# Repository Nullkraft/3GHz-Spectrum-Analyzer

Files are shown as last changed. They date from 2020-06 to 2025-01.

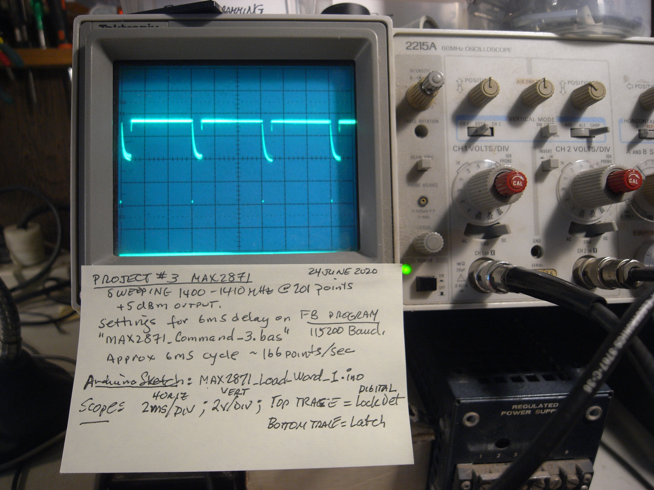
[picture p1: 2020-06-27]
Spectrum_Analyzer/Test_Data_24June2020/MAX2871_Sweep_1400-1410_201PTS.jpg

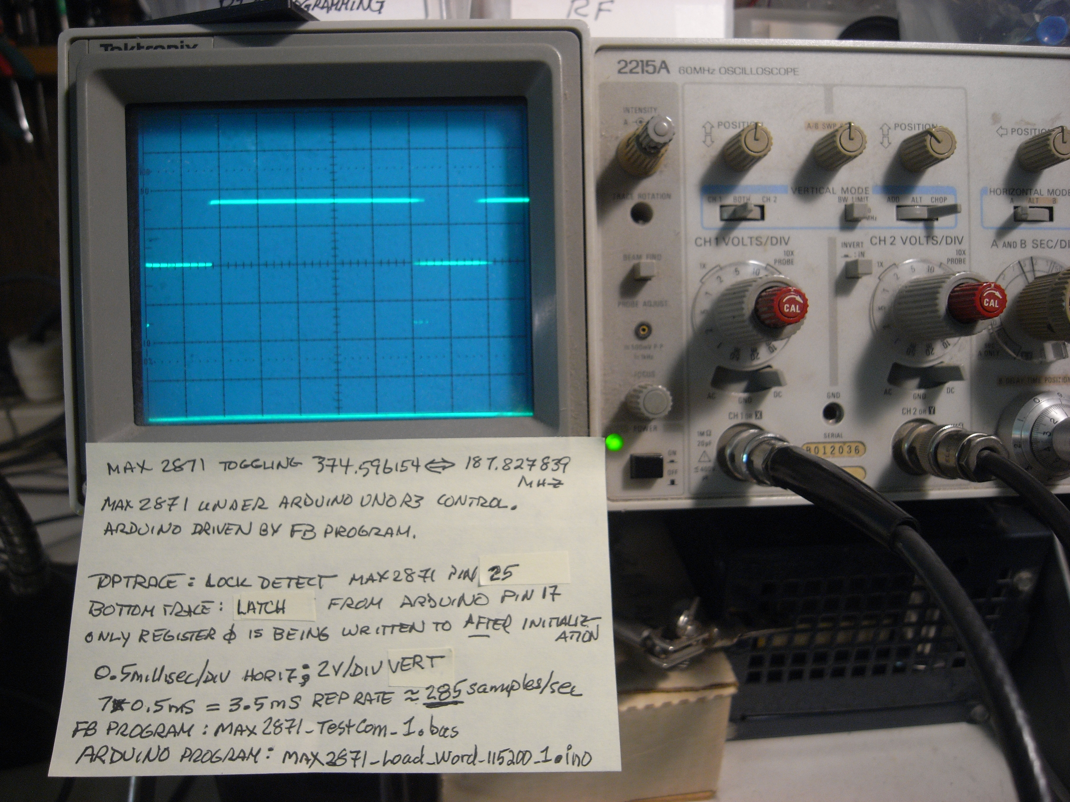
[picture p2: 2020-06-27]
Spectrum_Analyzer/Test_Data_24June2020/MAX2871_LockDet_AlternatingCode.jpg

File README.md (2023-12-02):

README for PROJECT#1 Spectrum Analyzer 22 June 2020- WN2A

A spectrum analyzer compatible with Arduino UNO R3 Microcontroller and others.

1) Schematics: are	spectrumwvi-page1.sch
					specrtumwvi-page2.sch
					specrtumwvi-page3.sch
					specrtumwvi-page4.sch
					specrtumwvi-page5.sch
    
   A small team with Mark Stanley and Mike Masterson using gEDA gschem schematics
    
2) This design is intended to meet the following preliminary specifications:
  * Frequency Range: 23.5 to 3000 MHz.
  * Spurious Free Dynamic Range: 72 dBC
  * Powered either by External +7 ~ +13V
  * Arduino driver provided allowing for serial command & control
  * Dual XTAL Reference allows minimizing Frac-N spurs.
  * Individual AZ1117 low-noise regulators for Digital, RF and VCO
  * Compatible with various Arduinos using the UNO pin arrangement

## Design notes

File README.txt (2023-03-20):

This is the First set of Documents for the Spectrum Analyser project 19Feb 2018

Goals:
1) Frequency Range: DC-3000 MHz
2) Dynamic Range: 72 dB min; 90 dB typ
3) Operating signal level <0dBm;
   Max RF Input +10dBm DC-48MHz ; +15 dBm 48-3000MHz
4) IF Bandwidths : A:~ 300KHz B:~ 7.5 KHz (Dual simultaneous IF's)
5) Power Supply requirement: +12 VDC at 1 A typ
6) Interface: Serial SPI Bus 3-wire . Clock and Data Common,
   LE signal is specific to the device being programmed.
7) Controllable from any Arduino UNO R3 or better microcontroller/ FPGA.

TODO's
1) Proof-Read this package
2) **DONE** - Determine Reference source,(i.e. Crystal Oscillator module at Frequency X)
3) Determine Shielding/Grounding requirements for PCB layout
4) Add information to the spread-sheet cost estimate (columns G and H).

In this package:
1) This README.pdf
2) SA_BlockDiagram.pdf
3) SA_Schematic_1.pdf
4) SA_Schematic_2.pdf
5) SA_Schematic_3.pdf
6) SA_Schematic_4.pdf
7) SA_Schematic_5.pdf
8) SA_Schematic_6.pdf
9) SA_Schematic_7.pdf
10) SA_Schematic_8.pdf

Most of the components used on this project are available, but the folder
for these is >27 Meg in size.

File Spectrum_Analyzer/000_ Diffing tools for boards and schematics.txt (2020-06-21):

From the Article: Visual diffs with gEDA, git, and GitHub
http://blog.benbergman.ca/2012/05/17/visual-diffs-with-geda-git-and-github/

Edit: Of course not 20 minutes after I publish this post I discover schdiff, a tool bundled with gEDA since the start of 2012 that is designed to hook into git-difftool to provide a visual diff of gschem .sch files. One format down, some more to go.

Edit 2: Less than a day later and I discover there is also a pcbdiff tool on my computer that came with gEDA pcb. In Arch Linux, it installs to /usr/share/pcb/tools/pcbdiff, but it is not in the path, so in my .bashrc I just added 'export PATH="$PATH:/usr/share/pcb/tools"' at the end.  I feel pcbdiff outputs images that are too low a resolution, plus it can't handle when the .pcb files change in physical size, so I might submit a patch or two. Long story short, now I just need to make a script that auto-calls these diff tools based on the file type.

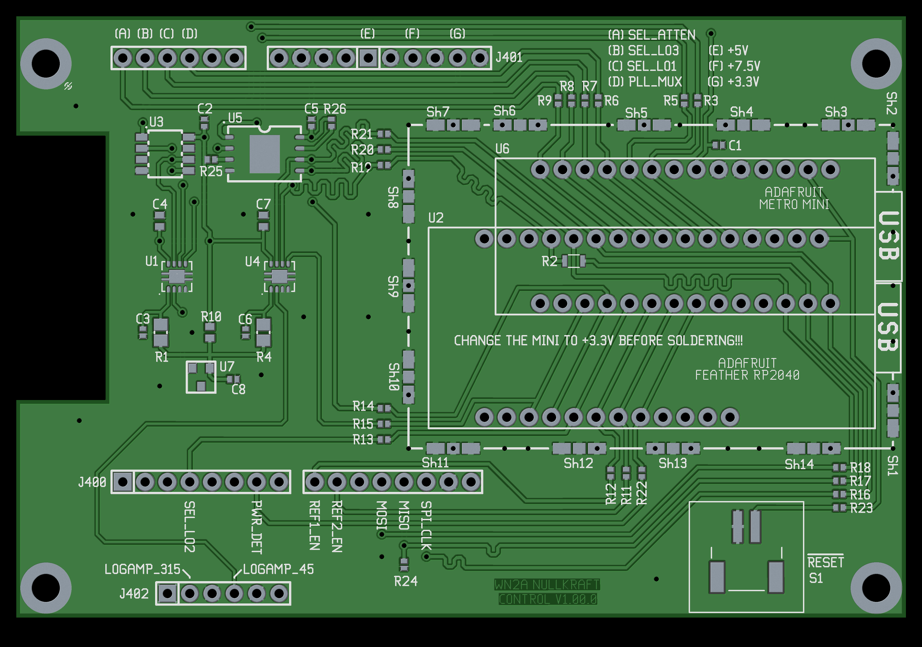
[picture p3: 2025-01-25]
Spectrum_Analyzer/Schematics/board_images/controlvwi_TOP.png

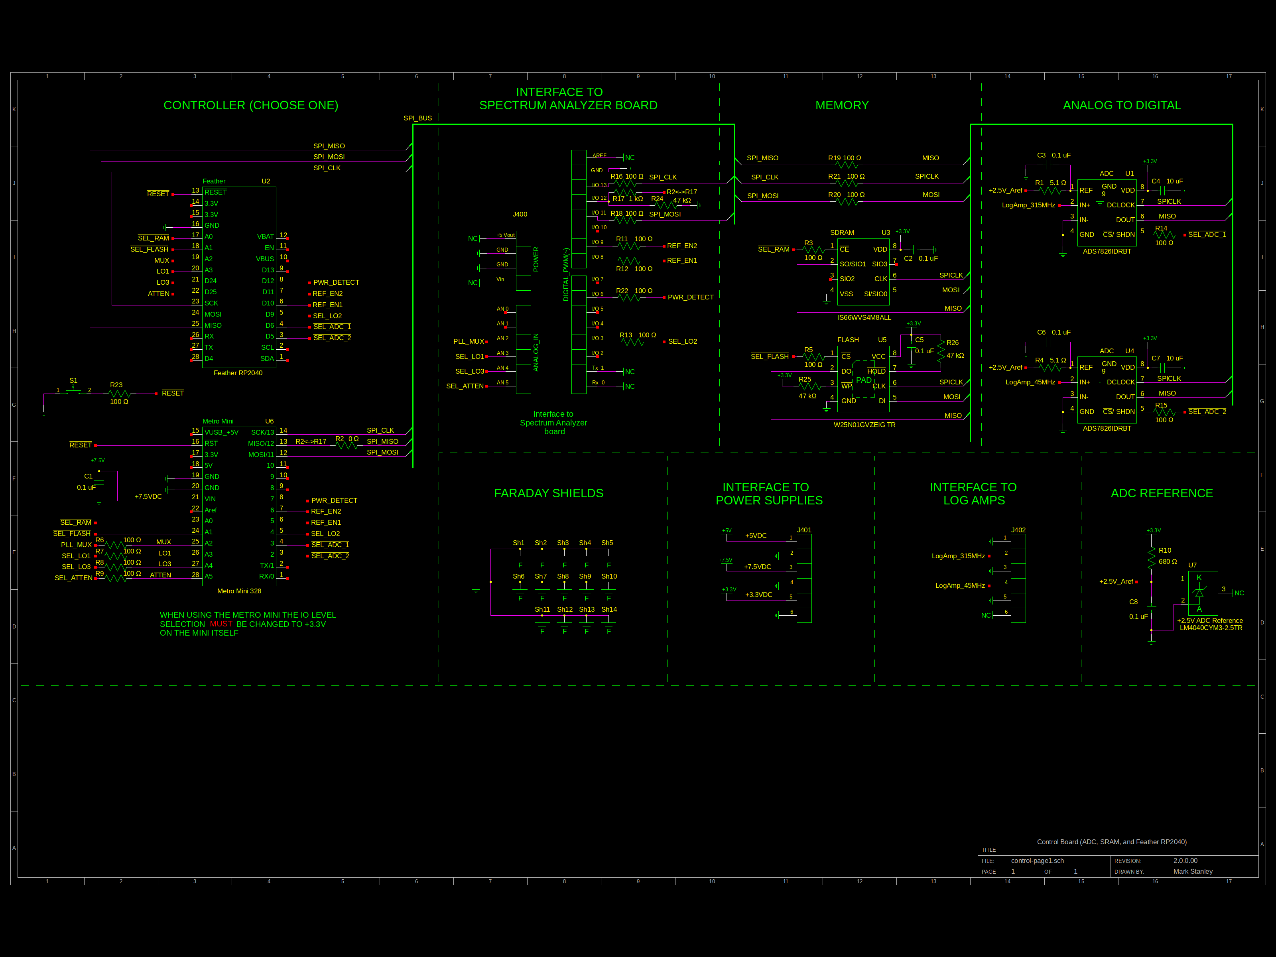
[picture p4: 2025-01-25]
Spectrum_Analyzer/Schematics/board_images/control-schem.png

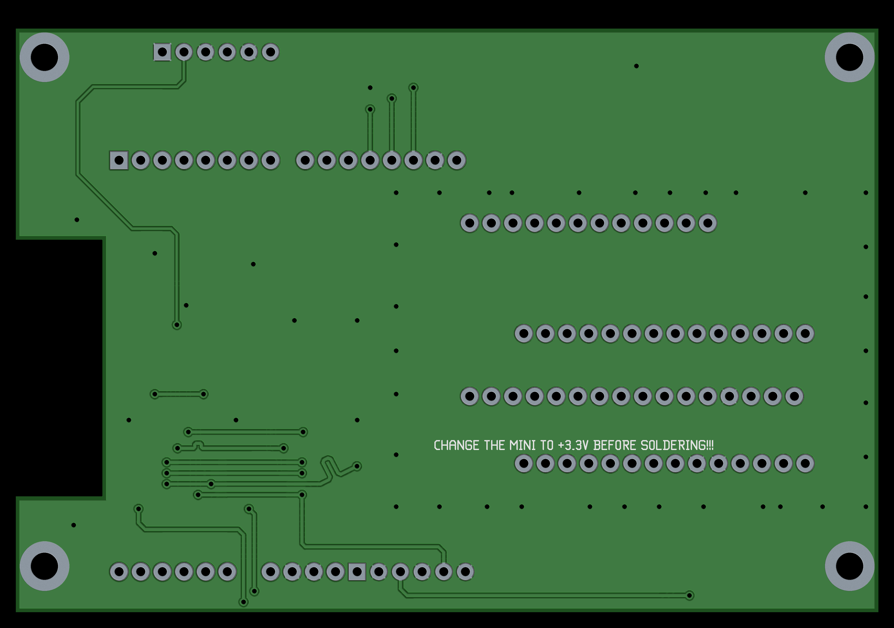
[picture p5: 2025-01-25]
Spectrum_Analyzer/Schematics/board_images/controlvwi_BOT.png

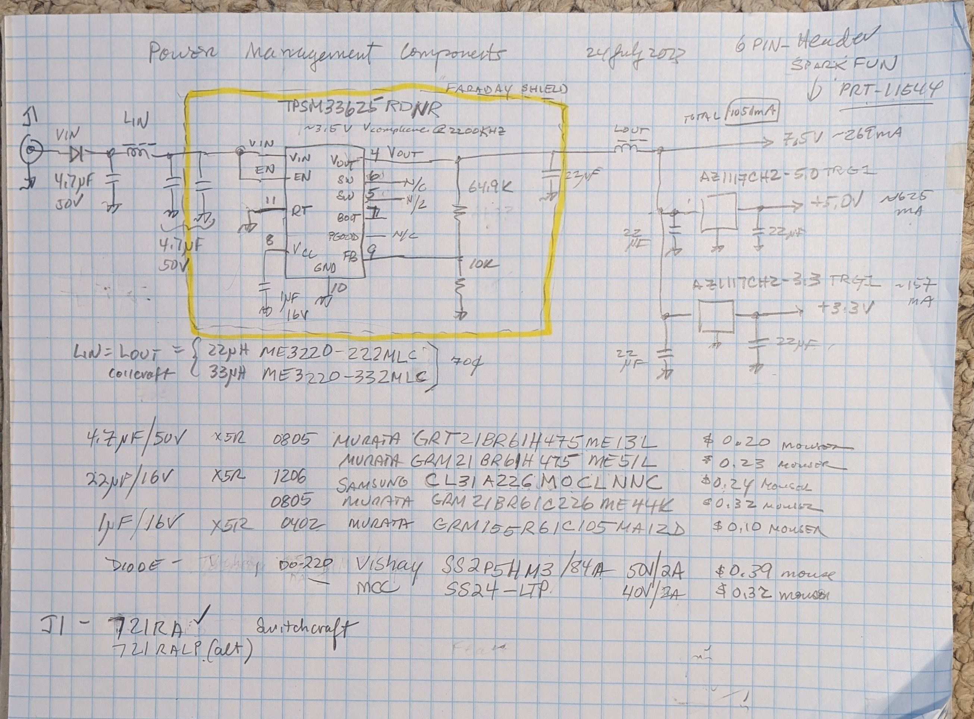
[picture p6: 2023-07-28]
Spectrum_Analyzer/Schematics/Schematics - Original Hand Drawn/Power Supply board.jpg

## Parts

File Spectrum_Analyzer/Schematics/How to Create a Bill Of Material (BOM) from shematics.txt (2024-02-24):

Create a Bill Of Material (BOM) from shematics

Open the terminal and enter the following commands :

   - cd /your_project

   - touch attribs : create a file that will contain the attributes you want to include in the BOM

   - touch bom.txt : Create the txt file

   - edit attribs to see what you want to add at your build. (value, footprint) Refdes is automatically added.

   - gnetlist -g bom2 -o bom.txt NiX1-V1-MB.sch (or the name of the actual file)

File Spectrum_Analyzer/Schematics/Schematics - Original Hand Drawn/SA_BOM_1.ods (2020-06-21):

SPECTRUM ANALYZER BOM : COMPONENTS
ITEM | DESCRIPTION | PART NO | MANF | REF DES | QTY | COST EA | COST EXT | SCH#
101 | Digital Step Atten | PE43711 | PSEMI | U101 | 1 |  |  | 1
102 | LOW PASS FILTERS | LFCN3000D+ | MCL | FL101,FL102 | 2 |  |  | 1
103 | GAIN BLOCKS | ERA-2SM+ | MCL | U102 | 1 |  |  | 1
104 | MIXER,DBM | SIM-83+ | MCL | U103 | 1 |  |  | 1
105 | CAPS,SMT BB | 530L104KT16T | ATC | C101,C102,C103,C107,C108 | 5 |  |  | 1
106 | CAPS, SMD 0.1uF,16V,X7R | 885012205037 | WURTH | C104,C106,C110 | 3 |  |  | 1
107 | CAPS,SMD,22pF,0402 | 885012005057 | WURTH | C105,C109 | 2 |  |  | 1
108 | RES, SMD, 1K | CRCW04021K00FKEDC | VISHAY | R101,R102,R103 | 3 |  |  | 1
109 | RES,SMD,51,1/8W | CRCW080551R0FKEA | VISHAY | R104,R105,R106,R107 | 4 |  |  | 1
110 | IND, SMD,22nH,0603 | 0603CS-R22XJEU | COILCRAFT | L101 | 1 |  |  | 1
111 | GAIN BLOCKS | ERA-1SM+ | MCL | U104 | 1 |  |  | 1
112 | IND, SMD,3.3nH,0402 | 0402CS-3N3XJEU | COILCRAFT | L102 | 1
 |  |  |  |  |  |  |  | 1
201 | GAIN BLOCKS | ERA-2SM+ | MCL | U201 | 1 |  |  | 2
202 | MIXER,ACTIVE | LTC5562IUC#TRPBF | ANALOG | U202 | 1 |  |  | 2
203 | BANDPASS FILTERS | 3600BP15M600 | JTI | FL201,FL202 | 2 |  |  | 2
204 | TRANSFORMER | TC1-1-43+ | MCL | T201 | 1 |  |  | 2
205 | TRANSFORMER | TC8-1-10LN+ | MCL | T202 | 1 |  |  | 2
206 | IND,SMD,10nH,0402 | 0402CS-10NXJEU | COILCRAFT | L201 | 1 |  |  | 2
207 | IND,SMD, 100nH,0603 | 0603CS-R10XJEU | COILCRAFT | L202,L203 | 2 |  |  | 2
208 | CAP,SMD,22pF,NP0,0402 | 885012005057 | WURTH | C201-C204;C211 | 5 |  |  | 2
209 | RES,SMD,51,1/8W | CRCW080551R0FKEA | VISHAY | R201,R207 | 2 |  |  | 2
210 | CAP, SMD 0.1uF,16V,X7R,0402 | 885012205037 | WURTH | C214,C216,C213,C206 | 4 |  |  | 2
211 | CAP,SMD,0.01uF,16V,X7R,0402 | 885012205031 | WURTH | C205,C210 | 2 |  |  | 2
212 | RES,SMD,300,0402 | CRCW0402300RFKED | VENKEL | R202-R205 | 4 |  |  | 2
213 | RES,SMD,36,0402 | CRCW040236R0JNED | VENKEL | R206 | 1 |  |  | 2
301 | FILTERS,SAW,315MHz | B39321B3741H110 | RF360 | FL301,FL302 | 2 |  |  | 3
302 | GAIN BLOCKS | ERA-2SM+ | MCL | U301,U302,U304 | 3 |  |  | 3
303 | MIXER,ACTIVE | LTC5562IUC#TRPBF | ANALOG | U303 | 1 |  |  | 3
304 | TRANSFORMER | TC8-1-10LN+ | MCL | T301 | 1 |  |  | 3
305 | FILTER,XTAL 45 MHz | ECS-75SMF45A7.5B | ECS | FL303,FL304 | 2 |  |  | 3
306 | RES,SMD 100, 0402 | CRCW0402100RJNED | VISHAY | R303 | 1 |  |  | 3
307 | RES,SMD 110,1/4w | CRCW1206110RFKEA | VISHAY | R301,R302,R309,R310,R311,R312 | 6 |  |  | 3
308 | IND,SMD,68nH,0603 | 0603CS-68NXJEU | COILCRAFT | L301-L304 | 4 |  |  | 3
309 | CAP,SMD,1.8pF,NP0, 0402 | GCM1555C1H1R82A16D | MURATA | C301,C302,C303,C304 | 4 |  |  | 3
310 | CAP,SMD,20pF,NP0,0402 | GCM1555C1H200JA01D | MURATA | C331,C332 | 2 |  |  | 3
311 | CAP,SMD,30pF,NP0,0402 | GCM1555C1H300JA01J | MURATA | C323,C324,C325,C326 | 4 |  |  | 3
312 | CAP,SMD,TBD pF | SAT |  | C327-C330 | 4 |  |  | 3
313 | CAP,SMD,0.01uF,X7R,0402 | 885012205031 | WURTH | C308-C311,C316,C317,C320,C322,C335-C338 | 12 |  |  | 3
314 | CAP,SMD,0.1uF,X7R,0402 | 885012205037 | WURTH | C321,C333,C334 | 3 |  |  | 3
315 | IND,SMD,36nH,0402 | 0402CS-36NXJEU | COILCRAFT | L305,L306 | 2 |  |  | 3
316 | IND,SMD,100nH,0603 | 0603CS-R10XJEU | COILCRAFT | L307,L308 | 2 |  |  | 3
317 | IND,SMD,390nH,0805 | 0805CS-391XjEU | COILCRAFT | L309,L311-L314 | 5 |  |  | 3
401 | Logarithmic Amplifiers | AD8307ARZ | ANALOG | U401,U402 | 2 |  |  | 4
402 | A/D CONV 2-CH | AD7887ARMZ | ANALOG | U403 | 1 |  |  | 4
404 | CAP,SMD,4.7pF,0402,25V,NP0 | 885012005038 | WURTH | C401 | 1 |  |  | 4
405 | CAP,SMD,47pF,0402,25V,NP0 | 885012005044 | WURTH | C402 | 1 |  |  | 4
406 | CAP,SMD,5pF,0402,50V,NP0 | GCM1555C1H5R0CA16D | MURATA | C403 | 1 |  |  | 4
407 | CAP,SMD,39pF,0402,50V,NP0 | GCM1555C1H390JA6D | MURATA | C404 | 1 |  |  | 4
408 | IND,SMD,82nH,0805 | 0805CS-820XJEU | COILCRAFT | L401 | 1 |  |  | 4
409 | IND,SMD,680nH,0805 | 0805CS-681XJEU | COILCRAFT | L402 | 1 |  |  | 4
410 | CAPS, SMD 0.1uF,16V,X7R | 885012205037 | WURTH | C405-C408;C411,C412 | 6 |  |  | 4
411 | RES, SMD, 1K | CRCW04021K00FKEDC | VISHAY | R403,R404 | 2 |  |  | 4
412 | RES, SMD,4.7 ohm | CRCW04024R70JNED | VISHAY | R401,R402,R405 | 3 |  |  | 4
413 | RES, SMD, 1K | CRCW04021K00FKEDC | VISHAY | R406-R409 | 4 |  |  | 4
501 | IC,PLL WITH VCO SYNTH 6800MHz | ADF4356BCPZ | ANALOG | U501 | 1 |  |  | 5
502 | OP AMP,RAIL TO RAIL | AD8605ARTZ | ANALOG | U502 | 1 |  |  | 5
503 | CAP,SMD,10pF,NP0,0402 | 885012005055 | WURTH | C501,C502,C503 | 3 |  |  | 5
504 | CAPS, SMD 0.1uF,16V,X7R | 885012205037 | WURTH | C504-C512 | 9 |  |  | 5
505 | CAP,SMD,10pF,NP0,0402 | 885012005055 | WURTH | C513 | 1 |  |  | 5
506 | CAP,SMD,1pF,NP0,0402 | CU10Y11R0BATUA | AVX | C514 | 1 |  |  | 5
507 | RES, SMD, 1K,0402 | CRCW04021K00FKEDC | VISHAY | R501-R503 | 3 |  |  | 5
508 | RES,SMD,560,0402 | CRCW0402560RFKED | VISHAY | R504 | 1 |  |  | 5
509 | RES,SMD,150k,0402 | CRCW0402150KJNED | VISHAY | R505 | 1 |  |  | 5
510 | CAP,SMD,10pF,NP0,0402 | 885012005055 | WURTH | C515-C516 | 2 |  |  | 5
511 | IND, SMD,3.3nH,0402 | 0402CS-3N3XJEU | COILCRAFT | L501 | 1 |  |  | 5
512 | CAP,SMD,1nF,0603,16V,NP0 | 885012006029 | WURTH | C517 | 1 |  |  | 5
601 | IC,PLL WITH VCO SYNTH 4400MHz | ADF4355-2BCPZ | ANALOG | U601 | 1 |  |  | 6
602 | OP AMP,RAIL TO RAIL | AD8605ARTZ | ANALOG | U602 | 1 |  |  | 6
603 | CAP,SMD,10pF,NP0,0402 | 885012005055 | WURTH | C601,C602,C603 | 3 |  |  | 6
604 | CAPS, SMD 0.1uF,16V,X7R | 885012205037 | WURTH | C604-C612 | 9 |  |  | 6
605 | CAP,SMD,10pF,NP0,0402 | 885012005055 | WURTH | C613 | 1 |  |  | 6
606 | CAP,SMD,1pF,NP0,0402 | CU10Y11R0BATUA | AVX | C614 | 1 |  |  | 6
607 | RES, SMD, 1K,0402 | CRCW04021K00FKEDC | VISHAY | R601-R603 | 3 |  |  | 6
608 | RES,SMD,560,0402 | CRCW0402560RFKED | VISHAY | R604 | 1 |  |  | 6
609 | RES,SMD,150k,0402 | CRCW0402150KJNED | VISHAY | R605 | 1 |  |  | 6
610 | CAPS,SMD,22pF,0402,NP0 | 885012005057 | WURTH | C615,C616 | 2 |  |  | 6
611 | CAP,SMD,1nF,0603,16V,NP0 | 885012006029 | WURTH | C617 | 1 |  |  | 6
701 | IC,PLL WITH VCO SYNTH 4400MHz | ADF4355-2BCPZ | ANALOG | U701 | 1 |  |  | 7
702 | OP AMP,RAIL TO RAIL | AD8605ARTZ | ANALOG | U702 | 1 |  |  | 7
703 | CAP,SMD,10pF,NP0,0402 | 885012005055 | WURTH | C701,C702,C703 | 3 |  |  | 7
704 | CAPS, SMD 0.1uF,16V,X7R | 885012205037 | WURTH | C704-C712 | 9 |  |  | 7
705 | CAP,SMD,10pF,NP0,0402 | 885012005055 | WURTH | C713 | 1 |  |  | 7
706 | CAP,SMD,1pF,NP0,0402 | CU10Y11R0BATUA | AVX | C714 | 1 |  |  | 7
707 | RES, SMD, 1K,0402 | CRCW04021K00FKEDC | VISHAY | R701-R703 | 3 |  |  | 7
708 | RES,SMD,560,0402 | CRCW0402560RFKED | VISHAY | R704 | 1 |  |  | 7
709 | RES,SMD,150k,0402 | CRCW0402150KJNED | VISHAY | R705 | 1 |  |  | 7
710 | CAPS,SMD,22pF,0402,NP0 | 885012005057 | WURTH | C715,C716 | 2 |  |  | 7
711 | CAP,SMD,1nF,0603,16V,NP0 | 885012006029 | WURTH | C717 | 1 |  |  | 7
801 | IC,REGULATOR,ADJ,1.5AMP,TO-220 | LM317T/NOPB | TI | U801-U803 | 3 |  |  | 8
802 | CAP,SMD,0.1uf, 25V,0603,X7R | 885012206071 | WURTH | C801-C803 | 3 |  |  | 8
803 | CAP,SMD,1.0uF,16V,0603,X7R | 885012206052 | WURTH | C804-C806 | 3 |  |  | 8
804 | RES,SMD,240,0603 | CRCW0603240RFKEB | VISHAY | R801-R803 | 3 |  |  | 8
805 | RES,SMD,1.2K,0603 | CRCW06031K21FKEB | VISHAY | R804 | 1 |  |  | 8
806 | RES,SMD,715,0603 | CRCW0603715RFKEA | VISHAY | R805 | 1 |  |  | 8
807 | RES,SMD,390,0603 | CRCW0603390RJNEB | VISHAY | R806 | 1 |  |  | 8
808 | DIODE,SMD,50V,2AMP | MURA105T3G | ONSEMI | D801 | 1 |  |  | 8

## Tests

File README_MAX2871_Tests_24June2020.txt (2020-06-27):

PROJECT#3 MAX2871 Synthesizer Tests 24June2020 WN2A

1) List of files in this folder:

   A) Arduino UNO R3 Code:  MAX2871_Load_Word_115200_1.ino
                    All tests reported here done with this program.
   
   B) FB Host Code:  Used for static (Manual) and dynamic (Toggling)
                   MAX2871_Load_Word_115200_1 (Linux Executable)
                   MAX2871_Load_Word_115200_1.bas  (FB source code)
                   
   C) FB Host Code: Used to Command a single frequency manually or sweep.
                   MAX2871_Command_3 (Linux Executable)
                   MAX2871_Command_3.bas (FB source code)
                   
   D) Screenshot of MAX2871_Command_3 running: MAX2871_Command_3_Window_1.png                
                   Note that the Arduino program sends an ID messgae to the Host 
                   program, after the Arduino is running.
                   Also, the sweep rate can be seen in this report as 
                   201 Points/Sweep x 204 sweeps= 41004 total sweeps, in 254 seconds
                   or ~161.4 points/second, or ~6.2 milliseconds/point.
                   That makes sense as the FB program was set for a 6 millisecond delay
                   resulting about the same rep rate. Setting the program for 5 or less
                   millisecond delay results is lost bytes. This as found to be a problem
                   most likely with the Arduino sketch, and the way it fetches serial
                   data. This results in limiting the sweep time. See comments (2B) below.
                   
   E) Oscilloscope trace of PROJECT#3 running with  A) and B).
                  File:  MAX2871_LockDet_AlternatingCode.jpg
                  This was the best case switching I observed, toggling between two
                  frequencies, about 3.5 milliseconds. Attempting to toggle any faster
                  than this resulted in breakup (lost bytes) from the Host to Arduino. 
                  This is related to the sweep time issue in D) . See note 2B.
                  
                   Both frequencies chosen in Fractional-N mode. Observing
                  either frequency (when manually i.e. statically toggled) looked clean
                  on my spectrum analyzer.  
                  
   F) Oscilloscope trace of PROJECT#3 running with  A) and C).   This is in the Frequency
                  Sweep mode, being driven by the FB program.
                  You can see the ~6.2 millisec rep rate. Setting the Host program for
                  5 or less millisec delay results in breakup.
                  
   G) MAX2871_1400-1410_201PTS_1.mpg. Video of the sweep mode A) and C). Sweeping 1400-1410MHz
                  201 points. 
                  
2) Notes:

   A) This part does give stable output measured on my Frequency Counter (23.5 to 500MHz+) and
      also viewed on an old HP8558B Spectrum Analyser to over 1500 MHz. Power was about +3dBm average.
      Spurious could not be measured accurately, due to equipment limitations, but looks better than
      -60 dBc.
      
   B) Both Laptops (Dell Mini Netbook and MacBook Pro) ran FreeBasic Host programs on Puppy Linux Slacko
      version 6.3.2. Both Laptops could deliver 115200 Baud Commands via the USB bus, with or without any
      delay added in the Host program. The Host program/Laptops showed no sign of breakup, and the Arduino
      Rx LED stays lit, regardless of the delay setting from 0 to 10 milliseconds.
        My suspicion is with my Arduino Sketch MAX2871_Load_Word_115200_1.ino (code snippet below):
        
        void loop() {
                while (Serial.available()) {  //wait for serial
              delayMicroseconds(1000);        // give it a millisec to fill buffer
              char c = Serial.read();         //read in a byte and convert to char
              readString += c;                // concatenate 
               }
          if (readString.length() >0) {
          z=readString.toInt();
          readString=""; 
          q=z/65536;
     delayMicroseconds(10);
     digitalWrite (strobe, LOW);
     digitalWrite (strobe, HIGH);
     delayMicroseconds(10);
     digitalWrite (strobe, LOW);
 Shifty(x);                                  // calls the Shift Out Routine
 }
}

          I commented out the serial receive lines above. While this code can receive each byte, and
      preform the byte>char>Integer conversions quickly and without any issues, the problem
      may be in identifying which is the first byte in a 32-bit word. The way this seems to work is that
      for a delay of ~5-6 milliseconds between words, it has no problem. The "blank time" easily
      allows for buffer clearing. Reducing this blank time to <5 milliseconds results in overwhelming
      the serial buffer (with this sketch code).
        To be sure, I do not use the Serial.print commands in this loop structure, and I do not enable 
      the serial monitor. That would have mde matters worse. Possibly, there is better Arduino code 
      that can be used here, so sweep times can be possibly improved toward ~3 milliseconds/point.
         The Shift Out Routine (Shifty(x)) was profiled on a scope and found to be plenty fast.
       More accurate measurements of this will be looked into, but the serial receive port code
       is much more suspect.

    C) Another little quirk noticed: In order for the Host Program to get control of the Arduino,
       this procedure was needed:
         a) Connect Arduino to Laptop via USB cable
         b) Open the Arduino IDE, check the Serial Port # (0,1,2,etc)
         c) Open the Serial Monitor. Now close the Serial Monitor and IDE.
         d) Run the FB program, either one B) or C) above.
         
         You didn't need to load any sketches or enter anything into the Serial Monitor,
         but it seemed weird that you need to open the IDE AND the Serial Monitor.
              
   D) Some thoughts about obtaining faster sweep rates by reducing USB communication and
       having the Arduino do the Fractional-N calculations.These are very computation heavy
       functions, being floating point and long unsigned data. It's very easy and efficent 
       done in FB code, because of a 32 (or 64 bit) operating system, 64 bit processor. This
       was verified in speed profiles, showing that the FB code was plenty fast. That was true
       on the Dell Mini Netbook also. 
         The addition of spur-reduction code will make computation more resource-hungry, both
         in program memory and speed. So while communication is faster when off-loading code
         to the Arduino, it will result in slower sweep times from a slower processor.
         It seems to be much easier to fix the Arduino sketch  1A) to get faster sweeps
         -OR- see if other Arduino boards have quicker serial periferials, keeping in mind
         periferial performance does not always track processor clock speeds.
         
Summary: From the standpoint of an inexpensive synthesizer ($11.53) with inexpensive Arduino controllers
          (~$9.95 or less ) providing a good 23.5-6000 MHz sweep generator with reasonable sweep
          times is very impressive. A slight improvement toward ~3 millsecond step time should make it very
          useful, especially for the PROJECT#1.

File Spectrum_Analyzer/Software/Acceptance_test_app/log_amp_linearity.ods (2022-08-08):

Data | dB | Vout
0 | 0 | 2.150
1 | 0.25 | 2.142
2 | 0.5 | 2.135
3 | 0.75 | 2.128
4 | 1 | 2.121
5 | 1.25 | 2.114
6 | 1.5 | 2.106
7 | 1.75 | 2.099
8 | 2 | 2.094
9 | 2.25 | 2.087
10 | 2.5 | 2.079
11 | 2.75 | 2.072
12 | 3 | 2.065
13 | 3.25 | 2.058
14 | 3.5 | 2.051
15 | 3.75 | 2.044
16 | 4 | 2.036
17 | 4.25 | 2.028
18 | 4.5 | 2.021
19 | 4.75 | 2.013
20 | 5 | 2.006
21 | 5.25 | 1.998
22 | 5.5 | 1.992
23 | 5.75 | 1.984
24 | 6 | 1.976
25 | 6.25 | 1.968
26 | 6.5 | 1.960
27 | 6.75 | 1.952
28 | 7 | 1.944
29 | 7.25 | 1.936
30 | 7.5 | 1.928
31 | 7.75 | 1.920
32 | 8 | 1.913
33 | 8.25
34 | 8.5
35 | 8.75
36 | 9 | 1.883
37 | 9.25
38 | 9.5
39 | 9.75
40 | 10 | 1.852
41 | 10.25
42 | 10.5
43 | 10.75
44 | 11 | 1.823
45 | 11.25
46 | 11.5
47 | 11.75
48 | 12 | 1.794
49 | 12.25
50 | 12.5
51 | 12.75
52 | 13 | 1.767
53 | 13.25
54 | 13.5
55 | 13.75
56 | 14 | 1.741
57 | 14.25
58 | 14.5
59 | 14.75
60 | 15 | 1.714
61 | 15.25
62 | 15.5
63 | 15.75
64 | 16 | 1.688
65 | 16.25
66 | 16.5
67 | 16.75
68 | 17 | 1.660
69 | 17.25
70 | 17.5
71 | 17.75
72 | 18 | 1.632
73 | 18.25
74 | 18.5
75 | 18.75
76 | 19 | 1.604
77 | 19.25
78 | 19.5
79 | 19.75
80 | 20 | 1.577
81 | 20.25
82 | 20.5
83 | 20.75
84 | 21 | 1.549
85 | 21.25
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

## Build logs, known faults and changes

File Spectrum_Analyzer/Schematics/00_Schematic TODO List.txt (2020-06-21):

1. Verify line widths can carry current to each component.
2. Do not connect external dc supplies to Arduino power pins.
3. Verify through hole Arduino header pin sizes.
4.

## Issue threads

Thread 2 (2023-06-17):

Compare Teensy against Metro Mini

Nullkraft, 2023-06-17:
The Teensy may be a viable high-speed option to replace the Metro Mini from Adafruit. The problem is RF noise so there should be a plan for sufficient shielding to be incorporated into the Arduino carrier board.

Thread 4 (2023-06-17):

Incorporate SRAM and Teensy onto digitizer board

Nullkraft, 2023-06-17:
Consider extending this sub board to also incorporate the power plug.  This is only a thought.

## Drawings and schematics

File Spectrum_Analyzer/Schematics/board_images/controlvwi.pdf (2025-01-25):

## /home/mark/projects/VaporWare_Inc./Project_#1/Spectrum_Analyzer/Schematics/controlvwi.pcb

## 1. Table of Contents (This Page) Created on Sat Jan 25 14:06:40 2025 2. top 3. ground 4. outline 5. plated-drill 6. componentmask 7. soldermask 8. topsilk 9. bottomsilk 10. toppaste 11. topassembly 12. bottomassembly 13. fab

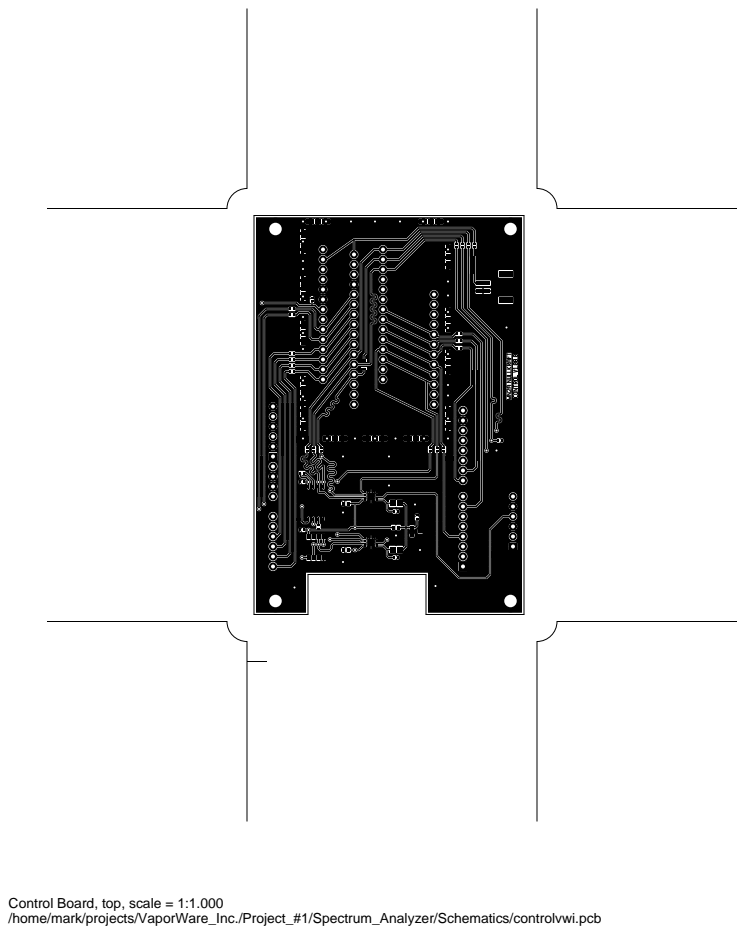
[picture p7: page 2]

Control Board, top, scale = 1:1.000

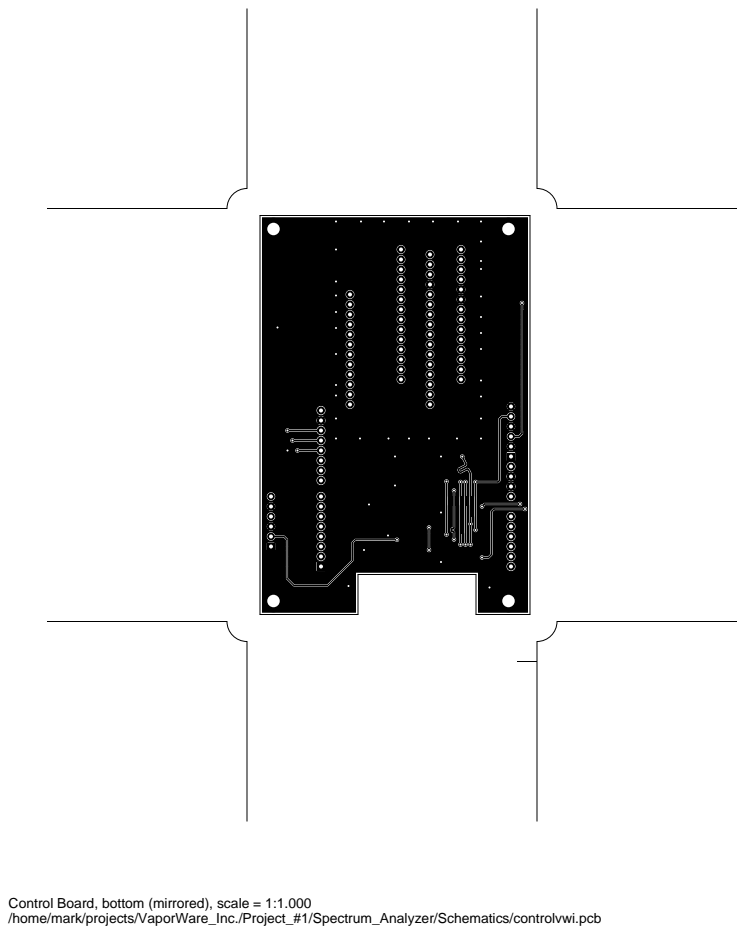
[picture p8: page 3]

Control Board, bottom (mirrored), scale = 1:1.000

Control Board, outline, scale = 1:1.000

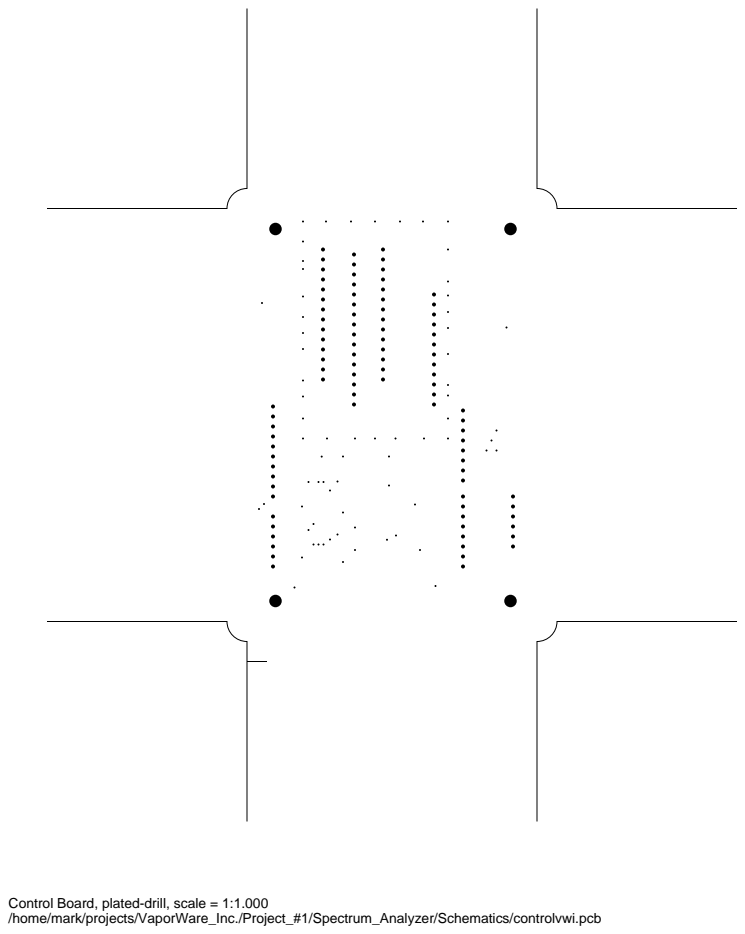
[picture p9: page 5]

Control Board, plated-drill, scale = 1:1.000

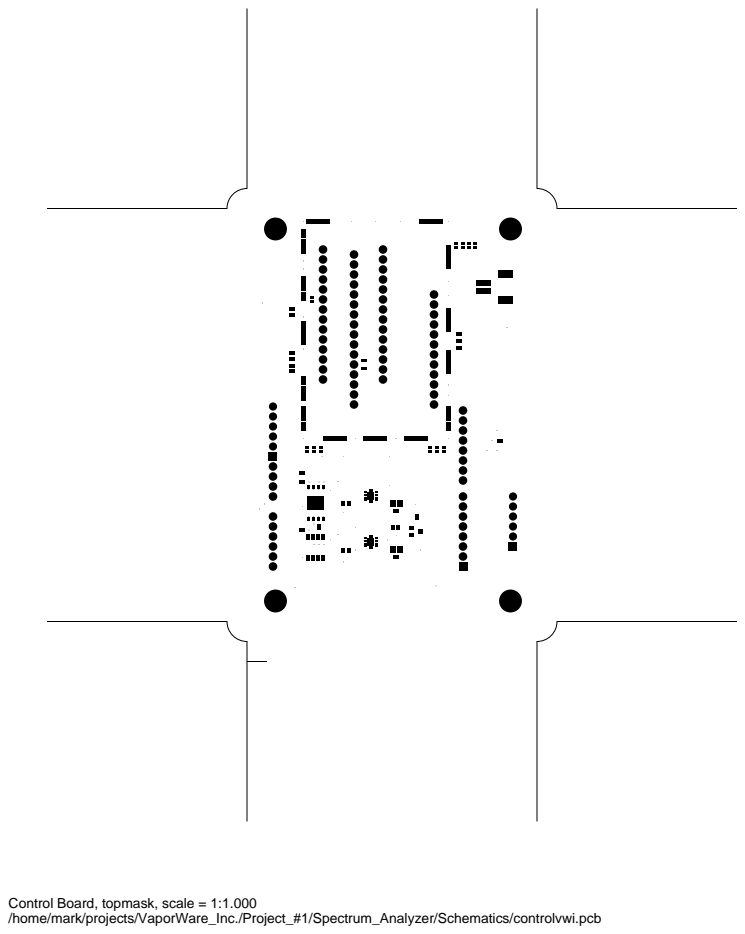
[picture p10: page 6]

Control Board, topmask, scale = 1:1.000

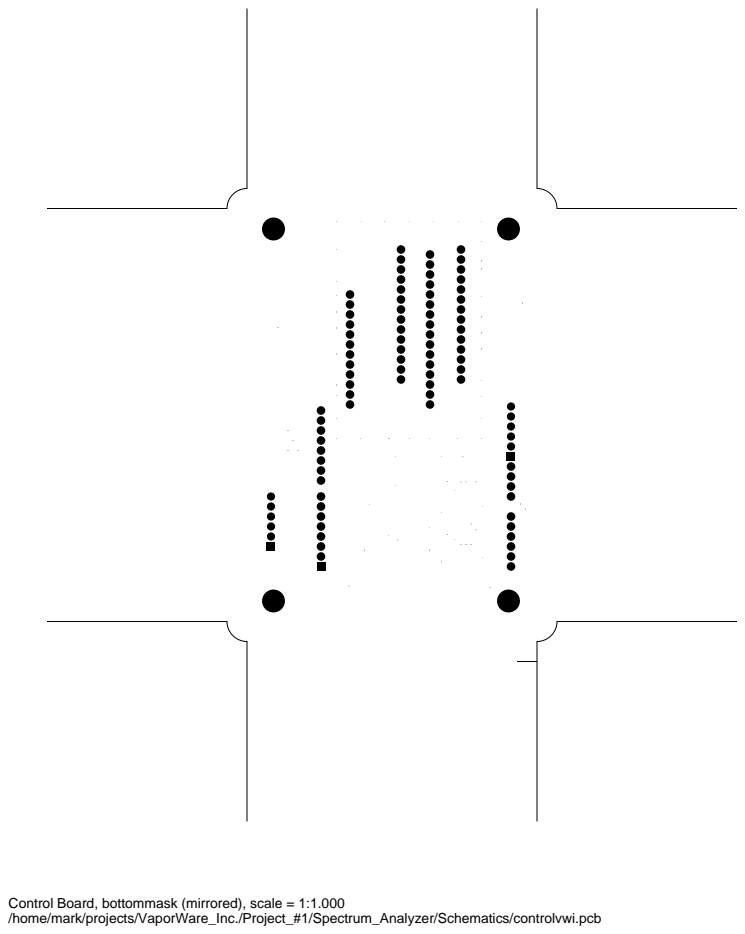
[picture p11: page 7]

Control Board, bottommask (mirrored), scale = 1:1.000

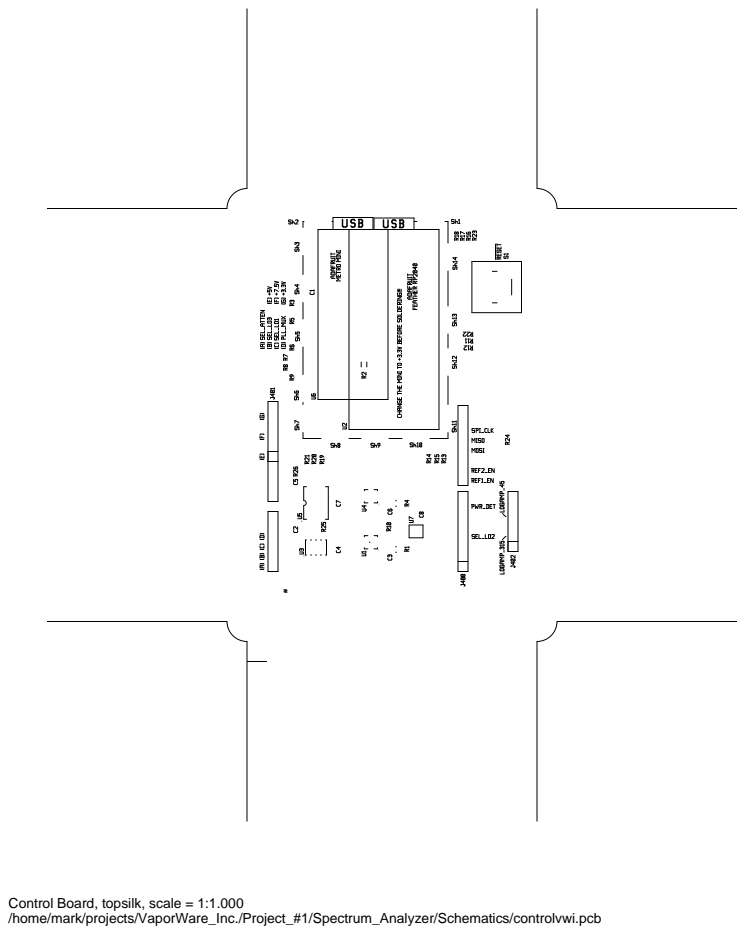
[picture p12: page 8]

Control Board, topsilk, scale = 1:1.000

Control Board, bottomsilk (mirrored), scale = 1:1.000

Control Board, toppaste, scale = 1:1.000

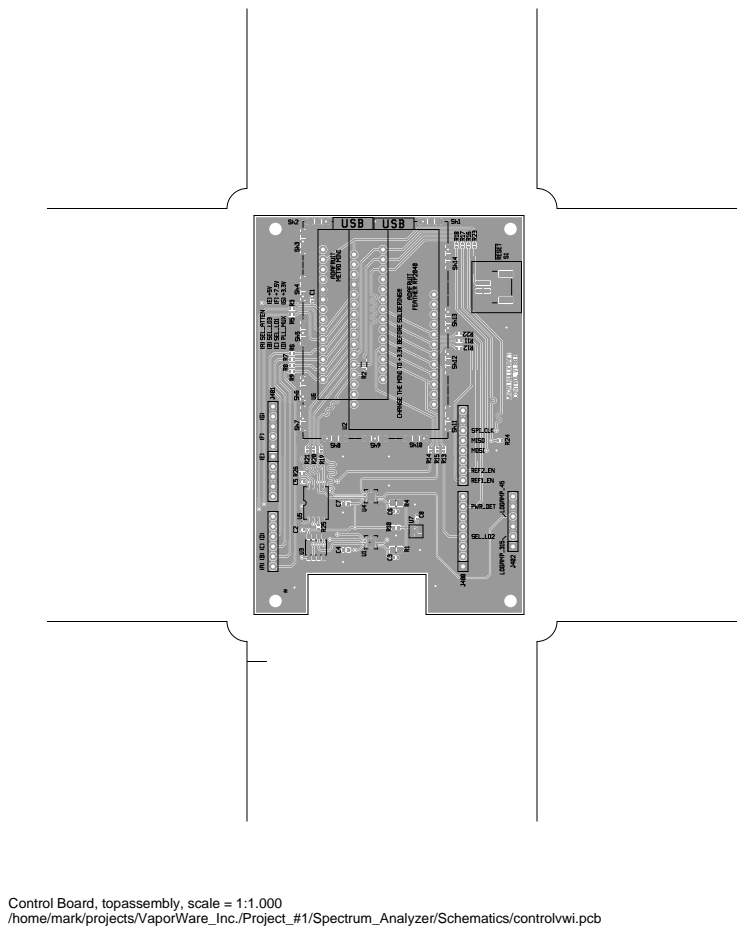
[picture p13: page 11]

Control Board, topassembly, scale = 1:1.000

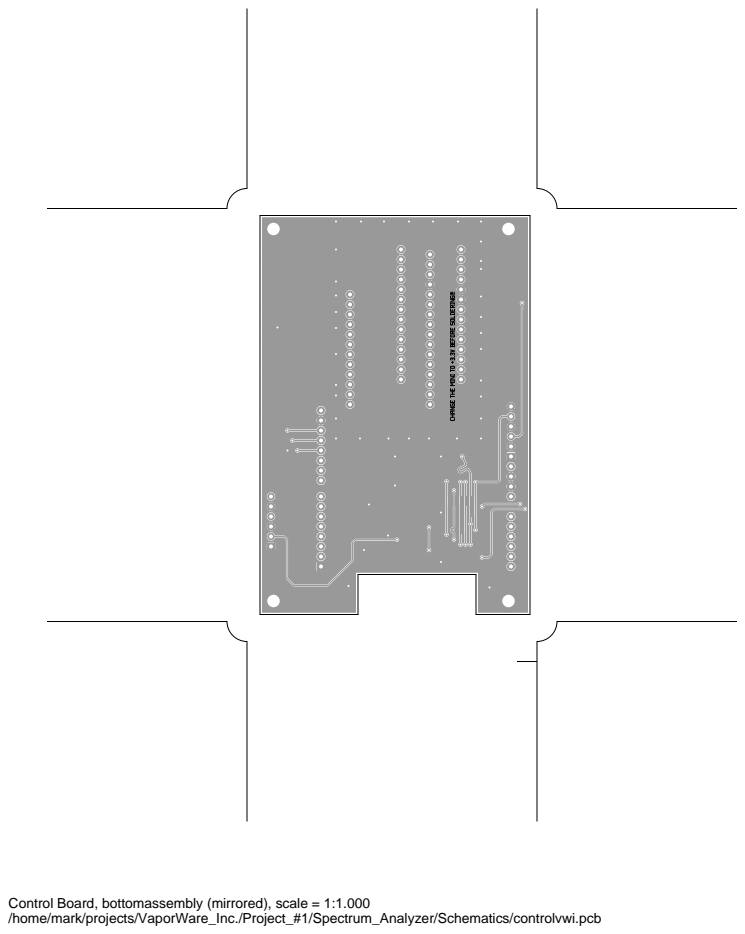
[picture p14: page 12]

Control Board, bottomassembly (mirrored), scale = 1:1.000

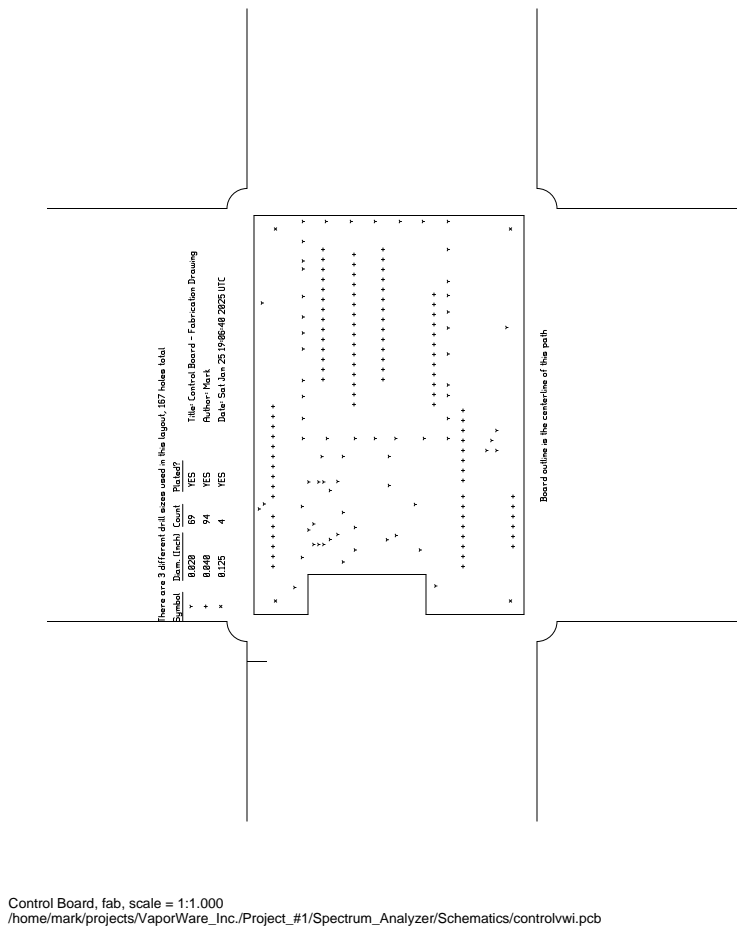
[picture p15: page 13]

Control Board, fab, scale = 1:1.000

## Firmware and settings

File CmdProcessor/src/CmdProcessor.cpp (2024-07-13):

/* Process incoming serial commands and device data registers
    for the LO's.

    All incoming serial data must be formed into 4 byte instruc-
    tions or data packets.  There  are  2  distinct  instruction
    types and one Data packet type. They are defined as follows:

    1. Specific Instruction - It consists of 16 bits of Embedded
       Data, 5 bits of Instruction, 3 bits of Address and 6 bits
       of a fixed value, 0xFF, Command Flag.

    2. Direct LO Instruction -  These consist of the values used
       to directly program the chip registers as defined  within
       the manufacturer's specification sheet.

    3. LO Data Packet -     These consist of a 12 bit Fractional
       Counter (F), a 12 bit Modulus Counter (M)  and  an  8 bit
       Integer Counter (N). A number of these will be sent based
       on the number sent in the Embedded Data section of an LO2
       or LO3 Specific Command.
*/

#include <Arduino.h>
#include <SPI.h>
#include "SpecAnn.h"

/////////// SERIAL COMMUNICATION PROTOCOL ///////////
#define SER_TIMEOUT 200 // Serial port gives up trying to read after 200 mSec
bool useBinary = true;  // Set this to true for binary mode, false for ASCII mode

/*           Serial Word with Command Flag:
    ,__________________________________________________,
   /_____________________/_________/_____/____________/|
   |       Embedded      | Command |Addr.|  Command  | | NOTE: Command Flag
   |       Data          |         |     |   Flag    | |        always = 0xFF
   |---------------------+---------+-----+-----------| |
   | xxxx_xxxx_xxxx_xxxx | xxxx_x  | xxx | 1111_1111 | |
   |_________________________________________________|/
*/
const uint8_t numBytesInSerialWord = 4;
uint32_t serialWord;                                  // Serial Word as 32 bits
uint8_t* serialWordAsBytes = reinterpret_cast<uint8_t*>(&serialWord);   // Serial Word as a byte array
const byte CommandFlag = 0xFF;  // Byte pattern to identify a 'Control Word'

uint8_t hi_byte;
uint8_t lo_byte;
uint16_t responseWord;
uint8_t* resp_byte = (uint8_t*)&responseWord;
bool sendIt = false;  // Guard flag to only send NEW data to the PC application
/////////// END SERIAL COMMUNICATION PROTOCOL ///////////

///////// Move to SpecAnn.h /////////
// unsigned long start_PLL_Lock_time;
// const int PLL_Lock_timeout = 500; // usec. Use 195 for testing some failures to lock.
// int LOCKED;
volatile uint16_t a2dAmplitude;
uint8_t* ampl_byte = (uint8_t*)&a2dAmplitude;
// uint8_t adc_pin;
/////////////////////////////////////

// A new Spectrum Analyzer
SpecAnn SA = SpecAnn();
// A new SpecificInstruction
SpecificInstruction SpecificInstr = SpecificInstruction();
uint16_t Data16;
byte cmdIdx;
byte Address;

// MARK: SETUP( ) ********
void setup() {
  #ifndef ARDUINO_SAMD_ZERO
    analogReference(EXTERNAL);
  #endif
  Serial.setTimeout(SER_TIMEOUT);
  Serial.begin(2000000);

  pinMode(LED_BUILTIN, OUTPUT);
  pinMode(SA.REF_LO_SEL, OUTPUT);
  pinMode(SA.REF_HI_SEL, OUTPUT);
  pinMode(SA.LO1_SEL, OUTPUT);
  pinMode(SA.LO2_SEL, OUTPUT);
  pinMode(SA.LO3_SEL, OUTPUT);
  pinMode(SA.PLL_MUX, INPUT);
  pinMode(SA.ATTEN_SEL, OUTPUT);
  digitalWrite(LED_BUILTIN, LOW);  // Make sure the LED is off

  SA.updateAtten(0x0, SA.ATTEN_SEL);   // Set 0dB on the digital attenuator
  SA.init_specann();
}


// MARK: LOOP( ) ********
uint16_t rleCount = 0;  // Initialize the external RLE count variable

void loop() {
    while (Serial.available()) {
        if (useBinary) {
            // Binary Communication for normal usage:
            Serial.readBytes(serialWordAsBytes, numBytesInSerialWord);  // serialWord == serialWordAsBytes
        } else {
            // ASCII Communication for testing Mike's code:
            serialWord = Serial.parseInt();
            if (serialWord == 0) {    // Serial timed out on SER_TIMEOUT
                continue;
            }
        }

        // Specific Instructions: Pg 2 of "Interface Standard 5 - Spectrum Analyzer.odt"
        if (serialWordAsBytes[0] == CommandFlag) {
            SpecificInstr.parseSpecificInstruction(serialWord);
            Data16 = SpecificInstr.getData();
            cmdIdx = SpecificInstr.getCommand();
            Address = SpecificInstr.getAddress();
            SA.selectHW(Data16, cmdIdx, Address, serialWord);
        }
        // General LO Instructions: Pg 9 of "Interface Standard 5 - Spectrum Analyzer.odt"
        // Programs the selected MAX2871 for LO2 or LO3 to the requested LO frequency.
        else {
            responseWord = SA.programHW(serialWord);
            sendIt = true;
        }

        if (sendIt == true) {
            if (responseWord != 0) {
                // Check if responseWord indicates an incremented RLE count
                if (responseWord == SA.rleIncremented) {
                    sendIt = false;  // Do not send the incremented RLE count message
                    continue;
                }

                // If rleCount exists, send the RLE count first
                if (rleCount > 0) {
                    uint16_t encodedRLE = SA.rleCountPacket | rleCount;
                    resp_byte[1] = encodedRLE >> 8;
                    resp_byte[0] = encodedRLE & 0xFF;
                    Serial.write(resp_byte[1]);
                    Serial.write(resp_byte[0]);
                    rleCount = 0;  // Reset the RLE count after sending
                }

                // Send the actual responseWord
                resp_byte[1] = responseWord >> 8;
                resp_byte[0] = responseWord & 0xFF;
                Serial.write(resp_byte[1]);
                Serial.write(resp_byte[0]);
            }
            sendIt = false;
        }
    }   /* End While serial available */
} /* End loop() */

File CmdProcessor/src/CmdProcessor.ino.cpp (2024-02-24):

/* Process incoming serial commands and device data registers
    for the LO's.

    All incoming serial data must be formed into 4 byte instruc-
    tions or data packets.  There  are  2  distinct  instruction
    types and one Data packet type. They are defined as follows:

    1. Specific Instruction - It consists of 16 bits of Embedded
       Data, 5 bits of Instruction, 3 bits of Address and 6 bits
       of a fixed value, 0xFF, Command Flag.

    2. Direct LO Instruction -  These consist of the values used
       to directly program the chip registers as defined  within
       the manufacturer's specification sheet.

    3. LO Data Packet -     These consist of a 12 bit Fractional
       Counter (F), a 12 bit Modulus Counter (M)  and  an  8 bit
       Integer Counter (N). A number of these will be sent based
       on the number sent in the Embedded Data section of an LO2
       or LO3 Specific Command.
*/

#include <SPI.h>

#ifdef PLATFORMIO
#include <Arduino.h>
#include "SpecAnn.h"
#endif

/////////// SERIAL COMMUNICATION PROTOCOL ///////////
#define SER_TIMEOUT 200 // Serial port gives up trying to read after 200 mSec
bool useBinary = true;  // Set this to true for binary mode, false for ASCII mode

/*           Serial Word with Command Flag:
    ________________________________________________
   [       Embedded      | Instr- |Addr.|  Command  ]  NOTE: Command Flag
   [       Data          | uction |     |   Flag    ]        always = 0xFF
   [---------------------+--------+-----+-----------]
   [ xxxx_xxxx_xxxx_xxxx | xxxx_x | xxx | 1111_1111 ]
*/
const uint8_t numBytesInSerialWord = 4;
uint32_t serialWord;                                  // Serial Word as 32 bits
uint8_t* serialWordAsBytes = reinterpret_cast<uint8_t*>(&serialWord);   // Serial Word as a byte array

/* All the values required by the spi_write() command */
uint32_t regWord;    // Holds the register contents to be written to the selected device

//*** Parsed values from the incoming 32 bit serial word ***
uint16_t Data16;  // 16 bits
byte Command;
byte Address;
const byte CommandFlag = 0xFF;  // Byte pattern to identify a 'Control Word'
uint8_t hi_byte;
uint8_t lo_byte;
/////////// END SERIAL COMMUNICATION PROTOCOL ///////////

///////// Move to SpecAnn.h /////////
unsigned long start_PLL_Lock_time;
const int PLL_Lock_timeout = 500; // usec. Use 195 for testing some failures to lock.
int LOCKED;
volatile uint16_t a2dAmplitude;
uint8_t* ampl_byte = (uint8_t*)&a2dAmplitude;
// uint8_t adc_pin;
/////////////////////////////////////

bool DEBUG = false;

// A new Spectrum Analyzer
SpecAnn SA = SpecAnn();
// A new SpecificInstruction
SpecificInstruction SpecificInstr = SpecificInstruction();

/******** SETUP *********************************************************************/
void setup() {
  #ifndef ARDUINO_SAMD_ZERO
    analogReference(EXTERNAL);
  #endif
  Serial.setTimeout(SER_TIMEOUT);
  Serial.begin(2000000);

  pinMode(LED_BUILTIN, OUTPUT);
  pinMode(SA.REF_LO_SEL, OUTPUT);
  pinMode(SA.REF_HI_SEL, OUTPUT);
  pinMode(SA.LO1_SEL, OUTPUT);
  pinMode(SA.LO2_SEL, OUTPUT);
  pinMode(SA.LO3_SEL, OUTPUT);
  pinMode(SA.PLL_MUX, INPUT);
  pinMode(SA.ATTEN_SEL, OUTPUT);
  digitalWrite(LED_BUILTIN, LOW);  // Make sure the LED is off

  SA.updateAtten(0x0, SA.ATTEN_SEL);   // Set 0dB on the digital attenuator
  SA.init_specann();
}


/******** MAIN LOOP ******************************************************************/
void loop() {
  while (Serial.available()) {
    if (useBinary) {
      // Binary Communication for normal usage:
      Serial.readBytes(serialWordAsBytes, numBytesInSerialWord);  // serialWord == serialWordAsBytes
    } else {
      // ASCII Communication for testing Mike's code:
      serialWord = Serial.parseInt();
      if (serialWord == 0) {    // Serial timed out on SER_TIMEOUT
        continue;
      }
    }

    /* Specific Instructions:
        Page 2 of "Interface Standard 5 - Spectrum Analyzer.odt"
    */
    if (serialWordAsBytes[0] == CommandFlag) {
      SpecificInstr.parseSpecificInstruction(serialWord);
      Data16 = SpecificInstr.getData();
      Command = SpecificInstr.getCommand();
      Address = SpecificInstr.getAddress();
      /* Hardware selection and operation */
      switch (Address) {
        case SA.Attenuator:
          SA.updateAtten(static_cast<uint8_t>(Data16), SA.ATTEN_SEL);
          break;
        case SA.LO1_addr:
          SA.spi_select = SA.LO1_SEL;
          SA.LO1.set_N_bits(Data16);                              // Set the new INT_N bits into Register 0
          regWord = SA.LO1.Execute(SA.adf4356CmdMap[Command], 0); // This selects from 1 of 7 adf4356 commands
          SA.LO1.update(regWord, SA.spi_select);                     // Write Reg[4] for set_TRI/set_DLD, ELSE Reg[6]
          SA.LO1.update(SA.LO1.Curr.Reg[0], SA.spi_select);          // followed by Reg[0] (REQUIRED by specsheet)
          break;
        case SA.LO2_addr:
          SA.adc_pin = SA.ADC_SEL_315; // Select the ADC that reads the output of the LO2 RF path
          SA.spi_select = SA.LO2_SEL;  // Select the pin for the MAX2871 used for LO2
          SA.updateLORegisters(SA.ptrLO2, SA.LO2_SEL, Command, serialWord);
          break;
        case SA.LO3_addr:
          SA.adc_pin = SA.ADC_SEL_045;
          /***** TODO: Why can't I feed SA.LO3_SEL directly into updateLORegisters() *****/
          SA.spi_select = SA.LO3_SEL;
          SA.updateLORegisters(SA.ptrLO3, SA.LO3_SEL, Command, serialWord);
          break;
        case SA.RefClock:
          SA.clkExecute(Command);
          break;
        case SA.MISC_addr:
          SA.miscExecute(SA.arduinoCmdMap[Command]);
          break;
        default:
          Serial.print(F("Requested Address:"));
          Serial.print(Address);
          Serial.println(F(" not found"));
      }   /* End switch(Address) */
    }
    /* General LO Instructions:
        Page 9 of "Interface Standard 5 - Spectrum Analyzer.odt" */
      // Programs LO2 or LO3 to the requested LO frequency.
    else {
      // M:  Set R[1], bits[14:3] to program the new value for M
      SA.LO->set_M_bits(serialWord);
      // N & F:  Set bits R[0], bits[22:15] for new N, and R[0], bits[14:3] for new F
      SA.LO->set_NF_bits(serialWord);
      // Program the selected LO starting with the higher numbered registers first
      SA.LO->update(SA.LO->Curr.Reg[1], SA.spi_select);
      SA.LO->update(SA.LO->Curr.Reg[0], SA.spi_select);
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

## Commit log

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2020-06-23 Restored files missing from project directories
    [Spectrum_Analyzer_gnetlist_BOM_3-28-20.csv]
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2020-06-29 Appended MAX2871 SigGen schematic to start the modifications for converting from the ADF4355
    [spectrumwvi-page1.sch, spectrumwvi-page2.sch, spectrumwvi-page3.sch]
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2020-06-30 Fixed +3.3VDC short to GND on pcb
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2020-06-30 Located every short caused by importing new MAX2871 circuitry
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2020-07-03 Change C342 & C345 from 22pF to 100pF with Wurth part number 885012205019
    [spectrumwvi-page3.sch]
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2020-07-03 Add 3 voltage regulators to spectrumwvi-page3.sch.
    +3.3V_RF_LO3, +3.3V_DIG and +3.3V_PLL - Part number AP7353
    [spectrumwvi-page3.sch]
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2020-07-09 gitignore Spec_Sheets folder to avoid redistributing manufacturers copy righted material.
2020-07-09 Connect ADF4356 pins 6, 17, 19 together in spectrumwvi-page1.sch
    1) U100 ADF4356 Pins 6,17 and 19 all connect together for +5 V.
    Pins 17 and 19 need to be connected to +5 (Same as pin 6). I think this is an old bug.
    2) Label "3500MHz_IF" change to "3600MHz_IF".
    The filter center frequency is actually 3600MHz. No Problem !
    We will shift frequency slightly and benefit from better image rejection. A good thing.
    [spectrumwvi-page1.sch]
2020-07-09 Change _3500 MHz_ label to _3600 MHz_ and part number AP7353 to AP7353-33CV4-7 in spectrumwvi-page2.sch
    3) The label shown as "3500MHz_IF" change to "3600MHz_IF".
    Also label "_3500 MHz_" change to "_3600 MHz_".
    4) AP7353 used at U204 should be AP7353-33CV4-7 to specify part
    as the 3.3 volt part, Bumped package.
    Also, Pin#3 should be shown on the symbol.
    [spectrumwvi-page2.sch]
2020-07-09 Change part num(s) AP7353 to AP7353-33CV4-7 (use 'git log' to see more)
    5) U308,U309,U310 same as #4 above.
    6) Delete R310. U303 pin 10 connects directly to ground.
    7) FL300 and FL301 : ECS-75SMF45A7.5B
    Pins 2 should not be grounded. Pin 2 should connect under the package
    (see datasheet) to pin 5.
    [spectrumwvi-page3.sch]
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2020-07-10 Continue with 5 Juyly 2020 punch-list fixes
    [spectrumwvi-page2.sch, spectrumwvi-page3.sch, spectrumwvi-page5.sch]
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2020-07-11 Can't resolve merge conflicts without being able to open both pcb file versions
2020-07-11 Apply correct 60 & 100 MHz oscillator footprints
    [spectrumwvi-page5.sch]
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2020-07-13 Swap LOAD_LO2 and DATA_LO2 to uncross pcb traces
    [spectrumwvi-page2.sch]
2020-07-14 New MAX2871 local oscillator pcb layout complete
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2020-07-29 Correct R217, R218, R320 and R321 part number to CRCW04021K50FKEDC
    [spectrumwvi-page2.sch, spectrumwvi-page3.sch]
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2021-06-03 Connect all chips to the SPI bus
    It turns out that the Arduino SPI bus is just under 60 times faster than the shiftOut() function. That means even if I used direct port manipulation to parallelize communications with the chips they 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
    [digitizer-page1.sch, pwrsupvwi-page1.sch, spectrumwvi-page2.sch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]
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2021-06-06 Rename footprint and symbol folders before fixing gafrc and project file settings
    [Digikey Project 8209776 SpecAn BOM.ods, Mouser Project_Mar28_0116PM SpecAn BOM.ods, Spectrum_Analyzer_gnetlist_BOM_3-28-20.ods]
2021-06-06 Reset pcb footprint folder setting and added a note to the PCB on how to set it.
2021-06-06 Clean folders before changing over to the SPI bus and remapping the Arduino pins.
    On the last spin of the board, v2.0, FL300 and FL301 had incorrectly mirrored footprints. The transformer T200 was also rotated by 90 degrees. Testing also showed that the Arduino shiftOut() function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
    [SA_BOM.csv, SA_BOM1.csv, SA_BOM_not2.csv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]
2021-06-16 Remove tracks & traces for programming the ADF and MAX chips separately
    [digitizer-page1.sch, spectrumwvi-page1.sch, spectrumwvi-page2.sch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]
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2021-06-19 Create new layers for shield outlines.
    I need the centerline dimensions for the shields. They will be the starting point for the mechanical layout of the shields themselves. I'm putting them on a separate layer so they can be separated fr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
    [spectrumwvi.bottom.gbr, spectrumwvi.bottommask.gbr, spectrumwvi.bottompaste.gbr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]
2021-07-03 Fix footprint selection(s) for PCB.
    [spectrumwvi-page2.sch, spectrumwvi-page4.sch]
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2021-07-05 Make soldermask clear long strip-line sections to remove the 3.8 Dk from the RF traces.
    [spectrumwvi-page1.sch, spectrumwvi-page2.sch, spectrumwvi-page3.sch]
2021-07-06 Modified ADF83xx layout to allow the use of either the ADF8307 or ADF8310 logAmp chip
    [spectrumwvi-page3.sch]
2021-07-15 Placing via's around RF traces and components. Previous board design had floating copper that were re-radiating signals.
    [spectrumwvi-page3.sch, spectrumwvi-page4.sch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]
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2021-07-28 Add divider resistor to U103 pin 16 to shift level to 3.3v as per the manufacturers spec sheet.
    [spectrumwvi-page1.sch]
2021-08-01 Request Mike review moving C117 from bottom of board.
    Mike said that it is better to have all the supporting components of the LO's on the same side of the board under the same shield. But in this case it will lengthen the loop traces. So is it still be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
    [spectrumwvi-page2.sch, spectrumwvi-page3.sch]
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2021-08-07 Clean up traces in and around Sh401 to prevent accidental shorts during assembly.
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2021-08-29 Replace schematic symbol for T200 to better represent circuit performance
    [spectrumwvi-page2.sch]
2021-08-29 Fix 3 errors found when a DRC Check is conducted on the pcb layout.
2021-08-29 Update schematic Page Interconnect Symbols (bubbles) to reflect change from parallel shiftOut() to serial SPI bus.
    [spectrumwvi-page1.sch, spectrumwvi-page2.sch, spectrumwvi-page3.sch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]
2021-09-14 Modify footprints for FL100 and FL101 to match Suggested PCB Layout (PL-137) from the spec sheet for the LFCN3000D+ part number
    [Arduino Serial block transfer commands.ods, Questionable_SweepData_1.csv, Questionable_SweepData_1.ods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]
2021-09-30 File & Folder maintenance and Add new Arduino project for working with the new API V2
    [Command List_28Sept2021_1.ods, Sweep_1-3000MHz_59981pts_1_dBV.csv, Sweep_1-3000MHz_59981pts_1_dBV.ods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]
2021-09-30 Create Arduino program for processing 32 bit Control Words sent from a PC
    [Command List_28Sept2021_1.ods]
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2021-10-02 Add list of hardware commands from CommandList.ods to the CmdProcessor.ino Arduino sketch
    [Command List_28Sept2021_1.ods]
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2021-10-17 Remove U104 to reduce RF input gain and change R303, R304 and R305 footprint from 0603 to 0402
    [Command List_2October2021_3.ods, spectrumwvi-page1.sch, spectrumwvi-page3.sch]
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2021-10-18 Change schematic and pcb I.A.W. Engineering Change Notice - ECN_Project1_17Oct2021.ods
    During Test-&-Tune of the Ver 2.0 board several RF concerns were found and remedied. The schematic and PCB were updated using the solutions that were found on the Version 2 board.
    [spectrumwvi-page1.sch, spectrumwvi-page2.sch, spectrumwvi-page3.sch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]
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2021-10-23 Fix BOM listing of C318
    [Board Assembly.ods]
2021-10-24 Change part number for U302 and U306
    Due to the global chip shortage the AD8605ARTZ-R2 shipping date has slipped to Feb. 8, 2023. More than 16 months from now. The new part, MCP6L71T-E/OT, is a one-to-one replacement.
    [spectrumwvi-page3.sch]
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2022-01-03 Fix SPI.transaction to send high byte to low byte of 32 bit word in the proper sequence
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2022-11-13 File replaced by 'Instruction List 30-Oct-2022 5a.ods'
    [Instruction List_2October2021_4a.ods]
2022-11-25 Add PLL lock detection and timeout
    Problem: The PLL lock detection is inside a while-true loop. If for
    any reason the Spectrum Analyzer fails to achieve a lock then it
    will be stuck in an infinite loop.
    Solution: A timeout was added to bypass the infinite loop and the
    4 most significant bits of the ADC word are set to 0xF as a message
    to the user that the PLL failed to achieve lock.
    Note: There is also a DEBUG flag that allows you to bypass the lock
    detection. That allows the Arduino code to be debugged without the
    Spectrum Analyzer board being plugged in.
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2023-03-20 Added part missing part numbers to schematic symbols
    [spectrumwvi-page1.sch, spectrumwvi-page4.sch]
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2023-03-20 feat(CmdProcessor): Rename CmdProcessor.ino to .cpp to fix intellisense
    [CmdProcessor.cpp, SpecAnn.h]
2023-03-20 fix(CmdProcessor.cpp): Add maybe_unused disable unused label warning for LoopTop
    It's not needed as it depends on whether or not we choose to communicate
    in binary or ascii.
    [CmdProcessor.cpp]
2023-03-20 fix(CmdProcessor.cpp): Remove useless 'z' variable
    [CmdProcessor.cpp]
2023-04-27 fix(spectrumwvi-page1.sch): Replace LO1 ADF4356 with a MAX2871
    [spectrumwvi-page1.sch, spectrumwvi-page1A.sch]
2023-04-27 fix(spectrumwvi-page1.sch): Reconnect PLL_MUX netname to net 31900, 69600
    [spectrumwvi-page1.sch]
2023-05-04 refactor(LO1): Replace with MAX2871 chip
    [spectrumwvi-page1.sch, spectrumwvi-page2.sch, spectrumwvi-page3.sch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]
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2023-05-28 fix(digitizer_vwi.pcb): Recovered missing pcb file
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2023-06-24 fix(spectrumwvi.pcb): Resize PLL Lock test pads
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2023-07-02 fix(control_vwi.gsch2pcb): Fix footprint library path
2023-07-02 fix(pwrsupvwi.gsch2pcb): Fix footprint library path
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2023-07-02 fix(control_vwi.pcb): Increase board size for more features
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2023-07-03 fix(CmdProcessor.cpp): Change to a block comment
    [CmdProcessor.cpp]
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2023-07-06 fix(control_X): Restore file names
    [control-page1.sch]
2023-07-08 fix(pwrsupply_board): Shifted symbol back into position
    [pwrsupvwi-page1.sch]
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2023-07-10 fix(Adafruit_mini.sym): Changed USB label to VUSB_+5V
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2023-07-10 fix(control.pcb): Move traces from ground plane to top plane
2023-07-10 fix(Title_block): Move values back into title block
    [control-page1.sch]
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2023-07-11 fix(pcb): Remove all ground layer traces from under Arduino
    [control-page1.sch]
2023-07-11 fix(pcb): Move sel lines away from SPI bus lines
    [control-page1.sch]
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2023-07-12 fix(pcb): Add shield and resistors
    [control-page1.sch]
2023-07-13 fix(footprint): Shrink openings for 0402 resistors
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2023-07-14 fix(pcb): Cleanup and shrink pcb
    [control-page1.sch]
2023-07-14 fix(pcb): Reconnect all resized capacitors
    [spectrumwvi-page1.sch, spectrumwvi-page2.sch, spectrumwvi-page3.sch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]
2023-07-14 fix(pcb): Same as last push
2023-07-14 fix(+2.5V_Ref): Symbol and footprint corrected
2023-07-14 fix(+2.5_Ref): Change part# to LM4040CYM3-2.5TR
    [control-page1.sch]
2023-07-14 fix(SpectrumAnalyzer): Remove R102 & R107 level shifter
    [spectrumwvi-page1.sch]
2023-07-14 fix(SpectrumAnalyzer): Remove R112 & R114 level shifter
    [spectrumwvi-page1.sch]
2023-07-14 fix(SpectrumAnalyzer): Remove R318 & R320 level shifter
    [spectrumwvi-page3.sch]
2023-07-14 fix(SpectrumAnalyzer): Remove R214 & R218 level shifter
    [spectrumwvi-page2.sch]
2023-07-14 fix(SpectrumAnalyzer): Remove R404 & R405 level shifter
    [spectrumwvi-page4.sch]
2023-07-14 fix(SpectrumAnalyzer): Remove R400 & R401 level shifter
    [spectrumwvi-page4.sch]
2023-07-14 fix(SpectrumAnalyzer): Clean up lines after removing level shifters
    [spectrumwvi-page4.sch]
2023-07-14 fix(SpectrumAnalyzer.pcb): Remove unused level shifters
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2023-07-17 fix(capacitor_1.sym): Replace with capacitor-1_small.sym
    [spectrumwvi-page1.sch, spectrumwvi-page2.sch, spectrumwvi-page3.sch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]
2023-07-17 fix(control.sch): Change broken capacitor symbols to capacitor-1_small.sym
    [control-page1.sch]
2023-07-19 fix(checklist 16-July-2023): Implement proposed fixes
    [control-page1.sch, spectrumwvi-page4.sch]
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2023-07-21 fix(TPSM33625): Refactor symbol
    [pwrsupvwi-page1.sch]
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2023-08-19 Align the stack and swap +7 and +5 volts power pins
    [control-page1.sch, pwrsupvwi-page1.sch, spectrumwvi-page4.sch]
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2023-08-20 Rearrange components to remove 3D interference
    The shield, Sh1, interferes with the shield on the board above it.
    Move Sh1 closer to board edge to eliminate inteference. Plug J1
    is open through to the surface of the board so modify the foot-
    print to remove ground plane and any traces that might short to
    the pins when inserted.
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2023-08-23 Add a reset switch to the Control board
    Modify faraday_shield.fp to accept one more trace through the shield
    opening. Swap pins with REF_Enable pins and PWR_DET to eliminate
    jumper to other side of board.
    [control-page1.sch]
2023-08-23 Add 100 ohm resistor to reset line
    [control-page1.sch]
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2023-10-05 Refactor pwrsupply schematic to show front panel cables & devices
    Initially the schematic symbols were being shown on the board for
    items that would only be found on the front panel. To properly
    show the relationship of the panel mounted parts the symbols were
    made to be graphically displayed on the schematic which prevents
    them from being added to the PCB. Then 3 connectors were added to
    the PCB for ease of connection from the front panel components.
    The connectors are conn1 (for the power switch), conn3 for the
    power plug, and optionally conn2 (alternate power plug location).
    [pwrsupvwi-page1.sch]
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2023-10-05 spectrumwvi.pcb: swap C120 and C124 to match schematic
    It would have been easier to swap the components on the schematic
    without messing around with the board layout. However, the schem-
    atic provides a tool 'Autonumber' which can really mess up all
    the reference designators if used incorrectly at a later date.
    Moving the components on the PCB instead is slightly safer.
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2023-10-05 controlvwi files: Swap R20 and R21
    [control-page1.sch]
2023-10-14 Change size of block comment to fix code folding
    [CmdProcessor.cpp]
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2023-10-15 Clarify comment when triggering a failure-to-lock
    [CmdProcessor.cpp]
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2023-10-16 Add len_devices for number of items in enum devices.
    The giant switch-case statements in CmdProcessor.cpp are going to
    be replaced with arrays of function pointers. The number of
    functions in enum devices is needed for setting up the array of
    function pointers.
    [SpecAnn.h]
2023-10-16 Add ',' to final entry of each enum to prevent future errors
    [SpecAnn.h]
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2023-10-17 Remove unused noise_threshold and use F() macro for strings
    [CmdProcessor.cpp, SpecAnn.h]
2023-10-17 Fix memory leak - delete LO obj created by 'new'
    [CmdProcessor.cpp]
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2023-10-18 Fix - Changed R4 to 470 ohms
    [pwrsupvwi-page1.sch]
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2023-10-19 Remove initialize() functions replaced by begin() functions
    [SpecAnn.h]
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2023-10-20 Replace shield ground clear with Harwin shield clips
    [pwrsupvwi-page1.sch]
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2023-10-20 Replace shield ground-clear with Harwin shield clips
    [spectrumwvi-page4.sch]
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2023-10-22 Refactor PCB's to accomodate required gerber fixes
2023-10-23 Make changes necessary to accommodate gerber fixes
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2023-10-23 Remove unused NOISE_FLOOR booleans
    bool LAST_STATE;
    bool ABOVE_NOISE_FLOOR;
    bool BELOW_NOISE_FLOOR;
    These were planned for detecting whether a signal was above or
    below the noise floor. A 'count' of the number of signals below
    the noise floor would reduce return serial traffic by 98%
    [CmdProcessor.cpp, SpecAnn.h]
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2023-10-28 Remove function placeholders called unused()
    The placeholders were used so the serial 'Command' could be used
    as an index into the function-pointer-array. The result is tight
    coupling between the serial input from the user and the driver.
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2023-10-28 Refactor LO1.ADF4356Execute() to use adf4356CmdMap[]
    The ADF4356Execute() function-pointer-array was using Command as
    the index. This tightly coupled the PC software to the Arduino
    adf4356 driver. Add the array adf4356CmdMap[Command] to decouple
    Command from the driver
    [CmdProcessor.cpp]
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2023-10-28 Update CmdMaps with enums
    Without the enums to cross reference from the maps, to the driver
    function-pointer arrays, would be error prone.
    [CmdProcessor.cpp]
2023-10-28 Fix tight coupling between PC and driver function-pointer array
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2023-10-31 Add ref_clock function-pointer array to replace switch-case
    [CmdProcessor.cpp, SpecAnn.cpp, SpecAnn.h]
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2023-11-04 Replace digitalWrite()'s with intended function
    [CmdProcessor.cpp]
2023-11-04 Replace direct register manipulation with SA.ref_LO() function
    [CmdProcessor.cpp]
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2023-12-21 Fix Design Rule Violations
    These 2 PCB's had their traces widened using a script. The problem
    is that distances between different traces became to narrow for
    the manufacturer to keep separated when creating the boards.
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2023-12-23 Revert "Add TPS7A02 Flash, footprint and symbol"
    This reverts commit 334d636b733a5b4694995a21a6f37dde657ff6bb.
    [control-page1.sch]
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2023-12-23 Swap TPS7A0218YCHR=man-part-num to man-part-num=TPS7A0218YCHR
    [control-page1.sch]
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2023-12-24 Cosmetic cleanup of RF Board
    While I was trying to fix the issue where jlcpcb.com was failing to
    detect the 2 inner layers I thought part of the problem may have
    been due to layout issues. So I cleaned up anything that even
    looked close to problematic.
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2023-12-25 Fix tab pad for 3 terminal regulators on Power board
2024-01-01 Update BOM
    Review results require updating:
    1) U101 'device' change from OPAMP to RFAMP
    2) U102 'device' change from SIM-U762MH+ to MIXER
    (Either man-part-num of MCL-SIM-762H+ or SIM-762H+ is correct).
    3) Change U102 part number from SIM-U762MH+ to SIM-762H+
    [spectrumwvi-page1.sch]
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2024-02-11 Fix part number for U501
    The part number found in the schematic was incorrectly entered.
    It was ASFL1-66.666HMZ-EC-T and needed to be ASFL1-66.666MHZ-EC-T
    [spectrumwvi-page5.sch]
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2024-02-16 Revert "Remove redundant code from updateLORegisters"
    This reverts commit e4e7ad8a5076e66836b4693eadffffcc558119b0.
    This commit fails to run a sweep on the Spectrum Analyzer.
    [SpecAnn.cpp]
2024-02-17 Fix Arduino LED not working
    At: c5de2c7 Add setFrequency() function to MAX2871_LO class the
    Arduino LED stopped working. Commenting out SPI.begin() from the
    first_init() function fixes it.
2024-02-17 Add class CmdObj to SpecAnn.h
    This will be used to replace command flag processing in the
    CmdProcessor.cpp file
    [SpecAnn.h]
2024-02-18 Move switch (Address) into 'if (serialWordAsBytes[0] == CommandFlag)'
    The switch(Address) block was always outside the CommandFlag block.
    This was an error as the CommandFlag block parsed the serialWord
    into Address, Command, and Data which is used by the switch(Address)
    block.
    [CmdProcessor.cpp]
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2024-03-03 Fix !RFOUT_DIV_MASK to ~RFOUT_DIV_MASK
    Was using the boolean operator rather than the invert bits or NOT
    operator.
    [SpecAnn.cpp, adf4356.cpp, max2871.cpp]
2024-03-03 Fix compatibility with Arduino IDE
    The #include's for adf4356.h and max2871.h need to be enclosed in
    double quotes, not angle brackets, in order to be found by the
    Arduino IDE. Platformio doesn't care either way.
    [SpecAnn.h]
2024-03-10 Move 'switch (Address)' into SpecAnn.cpp
    This was in the main file, CmdProcessor.cpp. It's part of operating
    the spectrum analyzer and is too low level for day to day use.
    [CmdProcessor.cpp, SpecAnn.cpp, SpecAnn.h]
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2024-04-01 Fix PLL_Lock_timeout type from const int to const unsigned long int.
    [SpecAnn.h]
2024-04-01 Fix CmdProcessor.cpp sending too many data packets to PC application
    CmdProcessor should be handling *every* single Serial.write. There
    were 2 Serial.write() blocks in SpecAnn.cpp and this takes care of
    one of them. The problem was that the writes were at the top level
    of a while-loop and needed to guard against writing and rewriting
    old data to the serial port.
    [CmdProcessor.cpp]
2024-07-05 Flip sparkfun_11544 footprint right side up
2024-07-05 Schem: Add correct footprint for Control board ADCs
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2024-07-05 Schem: Fix man-part-number for C363 and C364
    The values for man-part-number were pasted from a web page which
    left some control characters at the front of the string causing
    the value to not be displayed.
    - Removed the control characters
    [spectrumwvi-page3.sch]
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2024-07-05 Schem: Remove documentation from Harwin shield clips symbol
    The last edit damaged page4 schematic and needed a second fixing.
    [spectrumwvi-page4.sch]
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2024-07-13 Fix QFN104EP footprint
2024-07-13 Fix SIM83+ footprint
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2024-07-13 Fix footprint for J401, 6 pin power supply header
    [pwrsupvwi-page1.sch]
2024-07-13 Fix units display from 3.3 uH to 3.3uH
    [pwrsupvwi-page1.sch]
2024-07-13 Reconnect J401 after fixing its footprint
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2024-07-13 Fix footprints for U200, U303, and U102
2024-09-04 Fix footprints for flash and ADC chips
    [control-page1.sch]
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2024-09-18 Fix error: potential for broken trace U303
2024-09-19 Fix DRC error: Update Harwin shield footprint
2024-09-19 Fix DRC error: potential for broken trace Sh419
2024-09-20 Fix DRC error: Line too thin Harwin clips
    [spectrumwvi-page4.sch]
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2024-12-08 Swap power plug polarities and LED source voltage
    [pwrsupvwi-page1.sch]
2024-12-10 Fix surface mount pad thermals
    [control-page1.sch]
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2024-12-20 Swap P1 and P2 refdes
    This aligns the Power Switch (P1) with the PWR SWITCH (CONN1)
    [pwrsupvwi-page1.sch]
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2025-01-25 Fix silk outline so not on pads
    [control-page1.sch]
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2025-02-14 BOM: Change U3 part number
    from IS66WVS4M8ALL, a 1.8v part, to IS66WVS4M8BLL, a 3.3v part.
    The circuit operates on 3.3v IO so this change prevents damage to
    U3.
    [control-page1.sch]
2025-02-14 Add missing signals to J400
    \SEL_FLASH, \SEL_SDRAM, \SEL_ADC1, and \SEL_ADC2. These signals are
    required if you want to use your own microcontroller.
    [control-page1.sch]
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2025-05-30 Change all 100Ω resistors to 1K (ERJ-2GEJ102X)
    This will give us added protection and we already know 1K works on
    the first Control board, that we did lots of white-wire changes to.
    The 1 K value doesn't guarantee protection, but its better than 100Ω.
    So R3, R5-to-R9, R11, R12, R14-to-R16, R18-to-R23 need changing.
    [control-page1.sch]
2025-05-30 Pwr board: R2 was an open resistor
    Replaced it, and now we have +7.5 volts.
    Note: The part number is correct: RT0402DRD0764K9L , but the
    value on the schematic says 64.9 (ohms). This should read 64.9K
    [pwrsupvwi-page1.sch]
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2026-02-18 Fix part# from AZ1117CD2 to AZ1117CH2
    The CD2 parts have the wrong pinout and footprint. The actual part should
    have been the CH2.
    [pwrsupvwi-page1.sch]
2026-02-20 Fix regulator chip (TPSM33625) alignment marks
    The alignment marks were displaced by several thousandths of an inch making
    it difficult to properly align the chip during manual assembly.
    Verified dimensions from the spec sheet and placed new alignment markers
    based on package size and centroid.
    [pwrsupvwi-page1.sch]
2026-02-20 Modify Harwin clips to use less solder
    There was too much solder which caused the clips to float on a bubble of
    solder instead of sitting flat. This caused minor alignment problems that
    should be fixed by using less solder.
    [pwrsupvwi-page1.sch]
2026-02-21 Fix R1, R2, and R3 too much solder
    Components don't sit flat on the board because they are floating on too
    much solder. Redesign footprint to reduce the amount of solder
    [pwrsupvwi-page1.sch]
2026-02-21 Fix diode D1 doesn't sit flat on PCB
    There's too much solder under the diode causing it to float. Change the
    footprint to reduce the solder paste area.
    [pwrsupvwi-page1.sch]
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
